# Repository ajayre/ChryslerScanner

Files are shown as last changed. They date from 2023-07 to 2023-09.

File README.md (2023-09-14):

# TJ Diag [][License]

GUI CCD 01

GUI SCI 01

GUI EngineTools 01

GUI BootstrapTools 01

<!----------------------------------------------------------------------------->

[Badge License]: https://img.shields.io/badge/License-GPLv3-blue.svg?style=for-the-badge
[GUI CCD 01]: https://chryslerccdsci.files.wordpress.com/2023/01/chryslerscanner_gui_ccd_01.png
[GUI SCI 01]: https://chryslerccdsci.files.wordpress.com/2023/01/chryslerscanner_gui_sci_01.png
[GUI EngineTools 01]: https://chryslerccdsci.files.wordpress.com/2023/01/chryslerscanner_gui_enginetools_01.png
[GUI BootstrapTools 01]: https://chryslerccdsci.files.wordpress.com/2023/01/chryslerscanner_gui_bootstraptools_01.png
[License]: LICENSE

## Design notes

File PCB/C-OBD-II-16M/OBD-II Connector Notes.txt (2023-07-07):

OBD-II CONNECTOR NOTES
======================

Right-angle OBD-II Connector sources (same part):
 - https://www.obd2-shop.eu/obd2pinblockmalepcbth-p-169.html?language=en
 - https://www.macchina.cc/catalog/parts/obd2-male-right-angle-pth-connector

Manufactured by:
 Comtech Electronic Co, Ltd. C-OBD-II-16M(90) - https://www.cct-elec.com/
 https://www.snapeda.com/parts/C-OBD-II-16M/Comtech%20Electronic%20Co.,%20LTD/view-part/

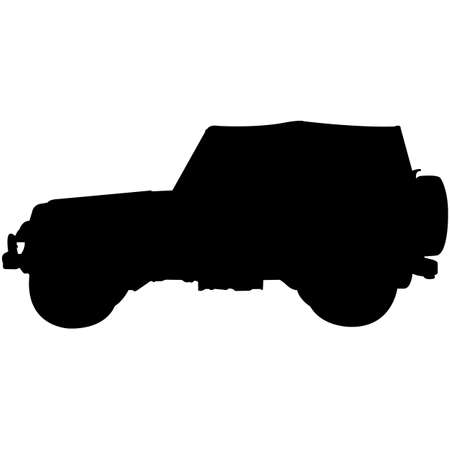
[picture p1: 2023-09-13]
PCB/Graphics/158078909-truck-silhouette-vector.jpg

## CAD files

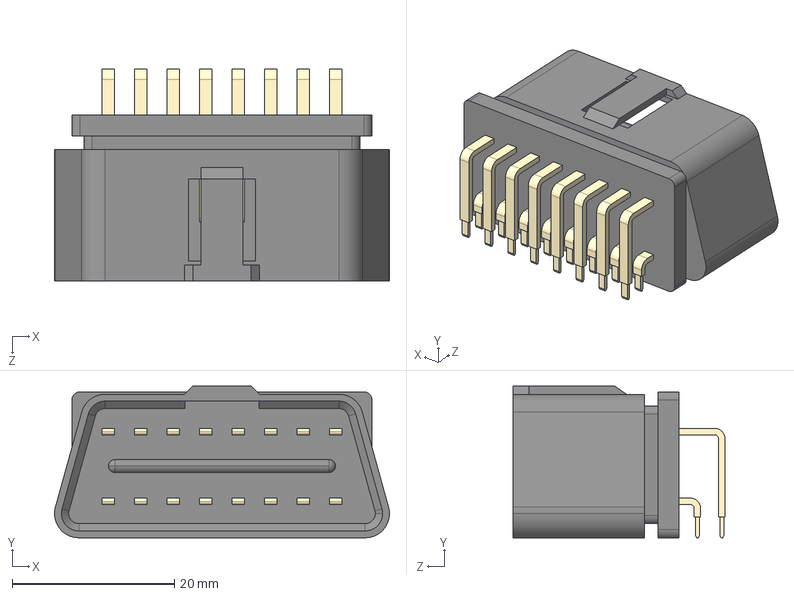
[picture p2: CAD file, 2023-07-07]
PCB/C-OBD-II-16M/C-OBD-II-16M.step
41.3 x 18.7 x 26.2 mm

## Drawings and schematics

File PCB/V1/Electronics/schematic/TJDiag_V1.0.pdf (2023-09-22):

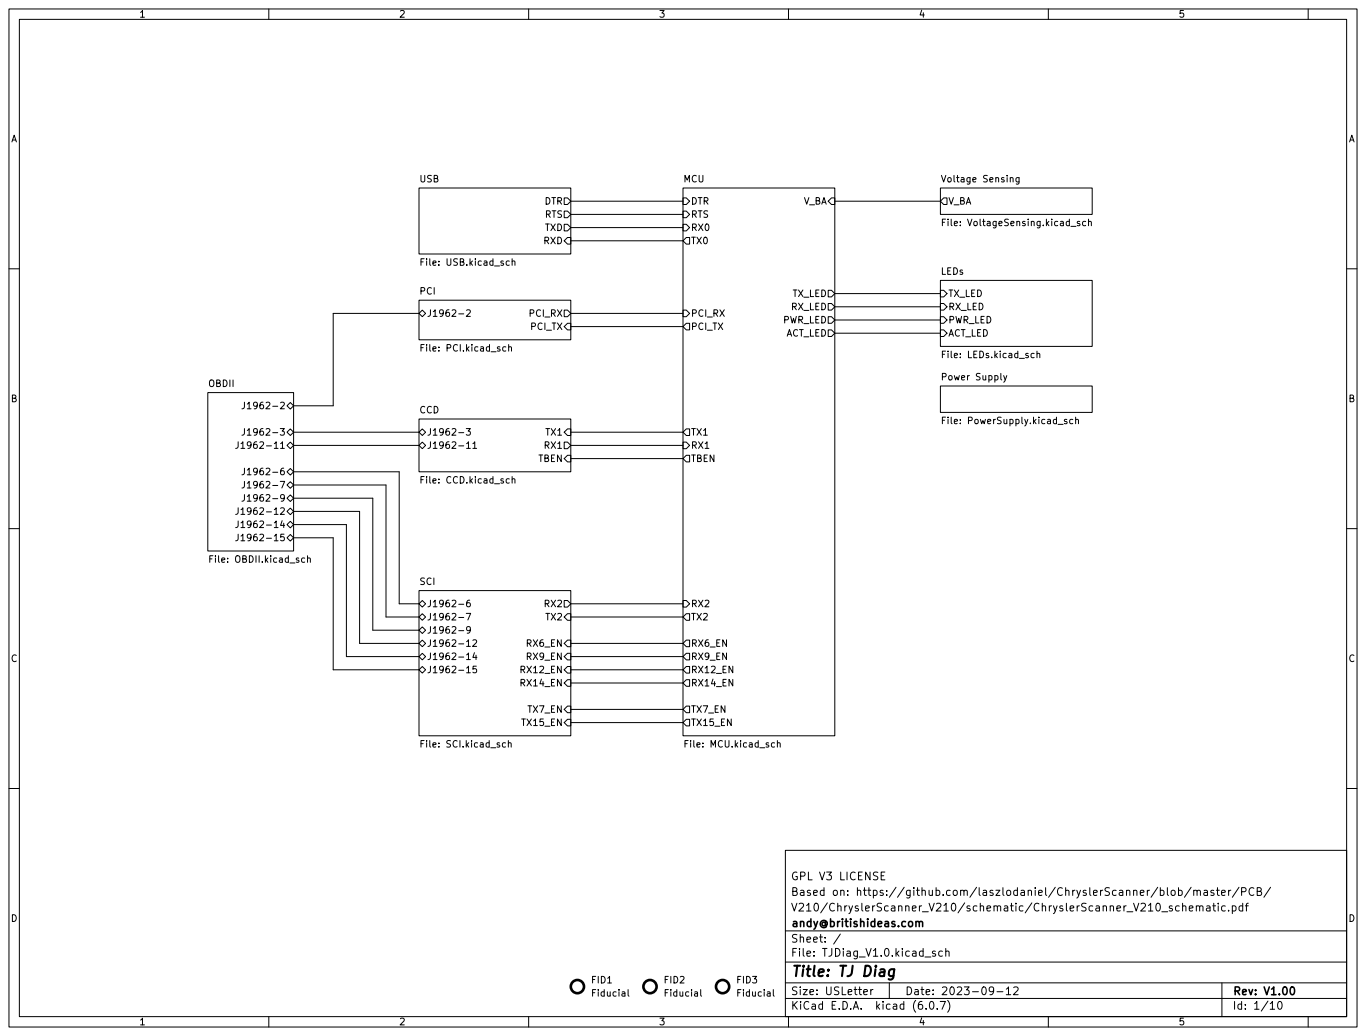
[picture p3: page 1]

LEDs File: LEDs.kicad_sch Power Supply

Based on: https://github.com/laszlodaniel/ChryslerScanner/blob/master/PCB/ GPL V3 LICENSE

V210/ChryslerScanner_V210/schematic/ChryslerScanner_V210_schematic.pdf
File: TJDiag_V1.0.kicad_sch Sheet: / andy@britishideas.com

Id: 1/10 Title: TJ Diag

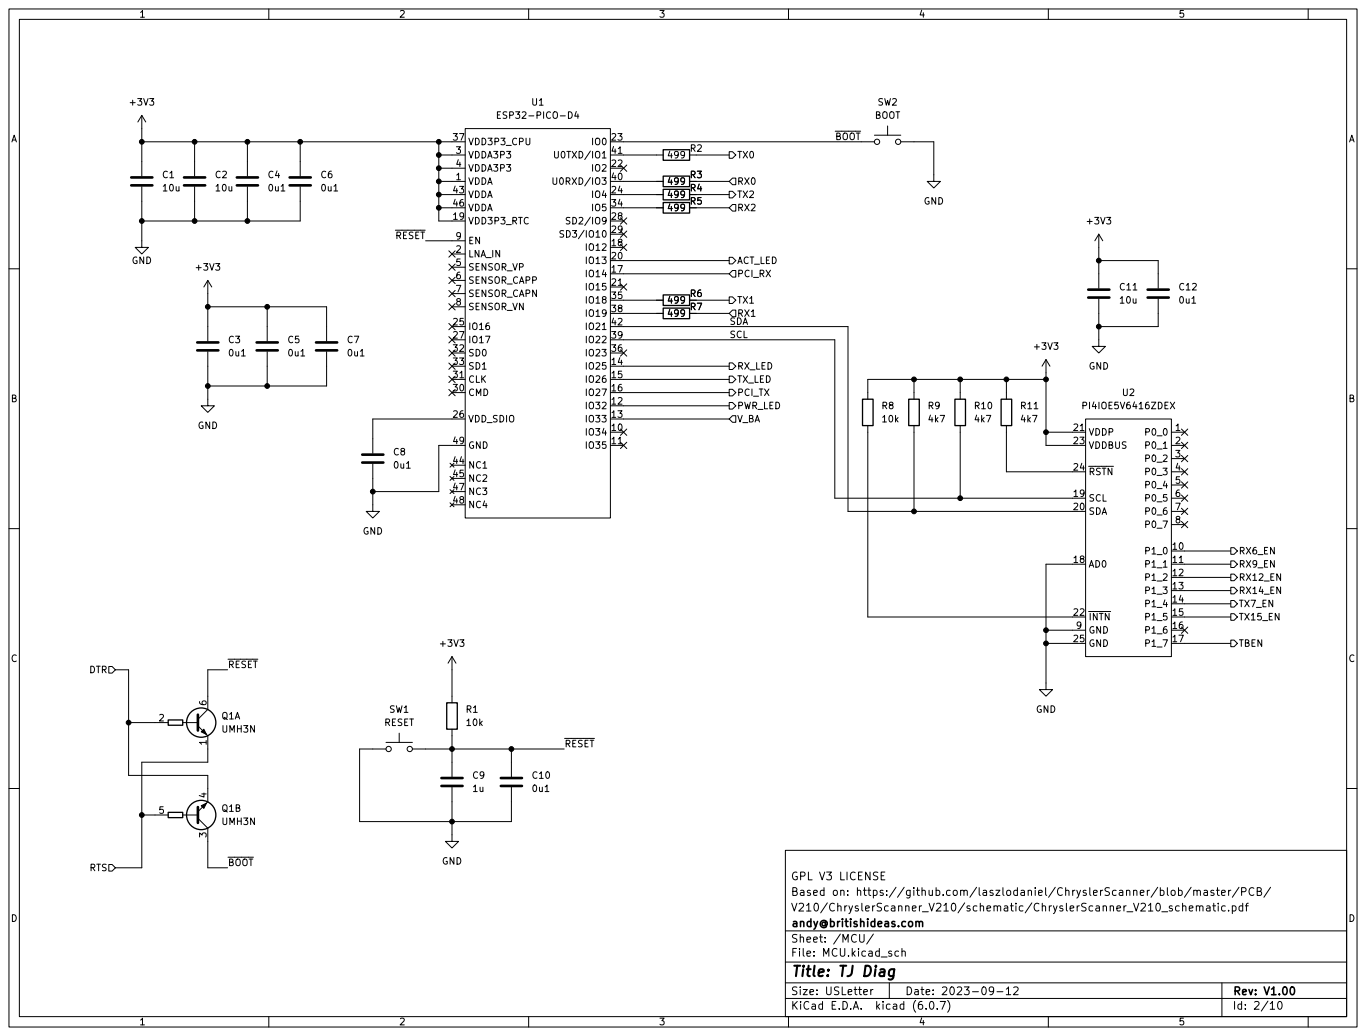
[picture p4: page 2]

Based on: https://github.com/laszlodaniel/ChryslerScanner/blob/master/PCB/ GPL V3 LICENSE

V210/ChryslerScanner_V210/schematic/ChryslerScanner_V210_schematic.pdf
File: MCU.kicad_sch Sheet: /MCU/ andy@britishideas.com

Id: 2/10 Title: TJ Diag

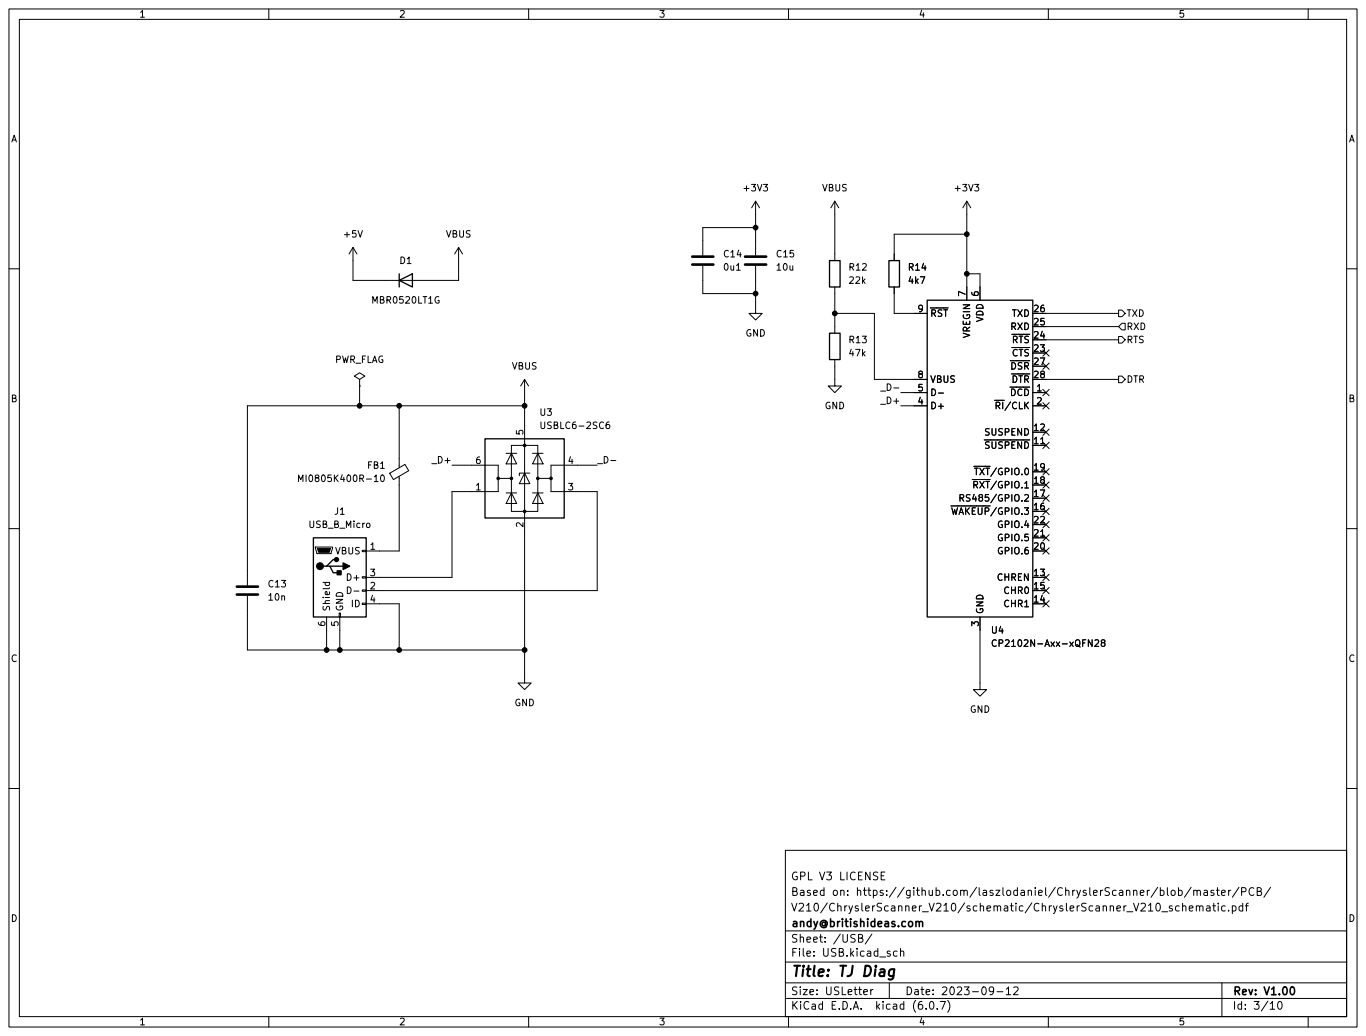
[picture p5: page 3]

Based on: https://github.com/laszlodaniel/ChryslerScanner/blob/master/PCB/ GPL V3 LICENSE

V210/ChryslerScanner_V210/schematic/ChryslerScanner_V210_schematic.pdf
File: USB.kicad_sch Sheet: /USB/ andy@britishideas.com

Id: 3/10 Title: TJ Diag

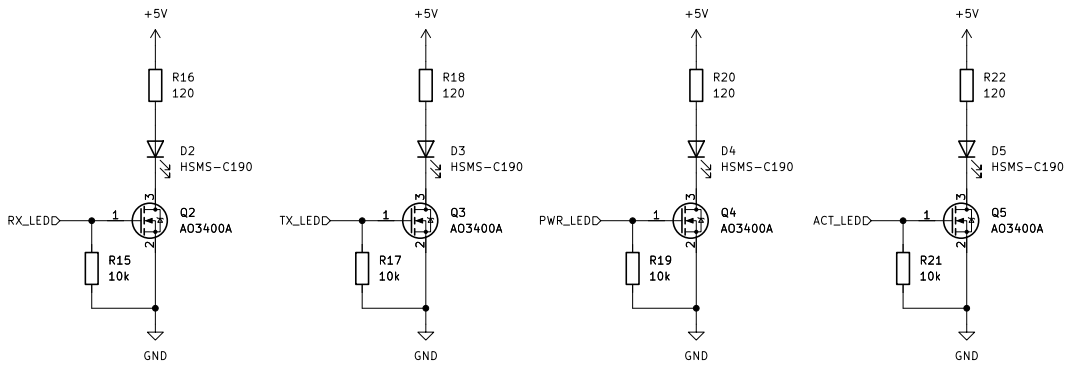
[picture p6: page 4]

Based on: https://github.com/laszlodaniel/ChryslerScanner/blob/master/PCB/ GPL V3 LICENSE

V210/ChryslerScanner_V210/schematic/ChryslerScanner_V210_schematic.pdf
File: LEDs.kicad_sch Sheet: /LEDs/ andy@britishideas.com

Id: 4/10 Title: TJ Diag

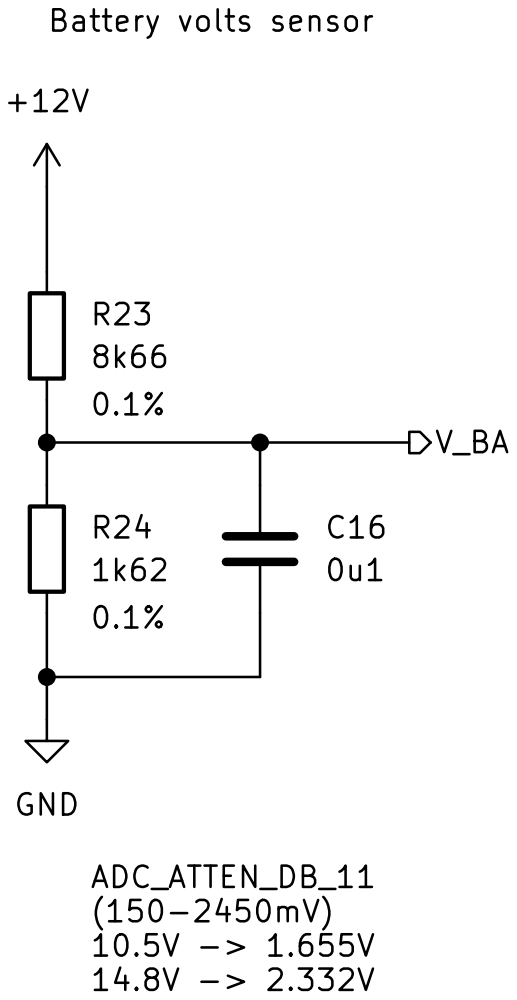
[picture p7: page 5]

Based on: https://github.com/laszlodaniel/ChryslerScanner/blob/master/PCB/ GPL V3 LICENSE

V210/ChryslerScanner_V210/schematic/ChryslerScanner_V210_schematic.pdf
andy@britishideas.com
Sheet: /Voltage Sensing/
File: VoltageSensing.kicad_sch
Id: 5/10 Title: TJ Diag

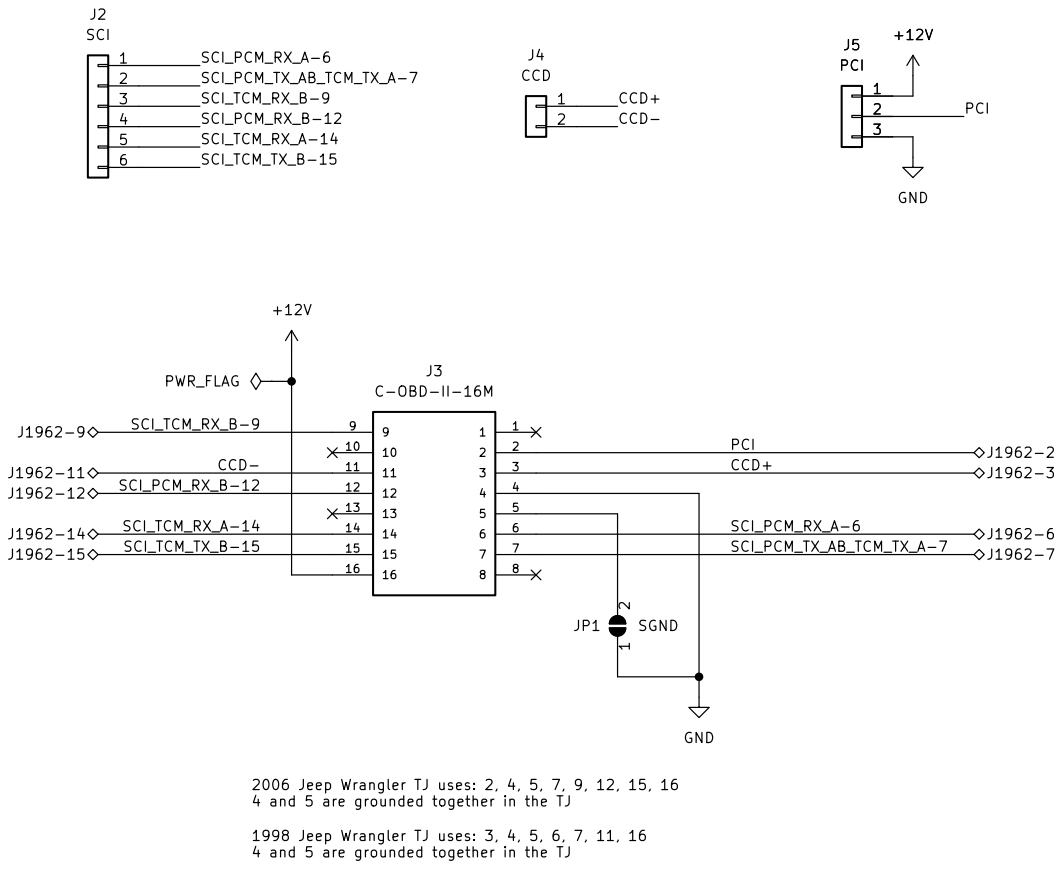
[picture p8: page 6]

4 and 5 are grounded together in the TJ

1998 Jeep Wrangler TJ uses: 3, 4, 5, 6, 7, 11, 16

Based on: https://github.com/laszlodaniel/ChryslerScanner/blob/master/PCB/ GPL V3 LICENSE

V210/ChryslerScanner_V210/schematic/ChryslerScanner_V210_schematic.pdf
File: OBDII.kicad_sch Sheet: /OBDII/ andy@britishideas.com

Id: 6/10 Title: TJ Diag

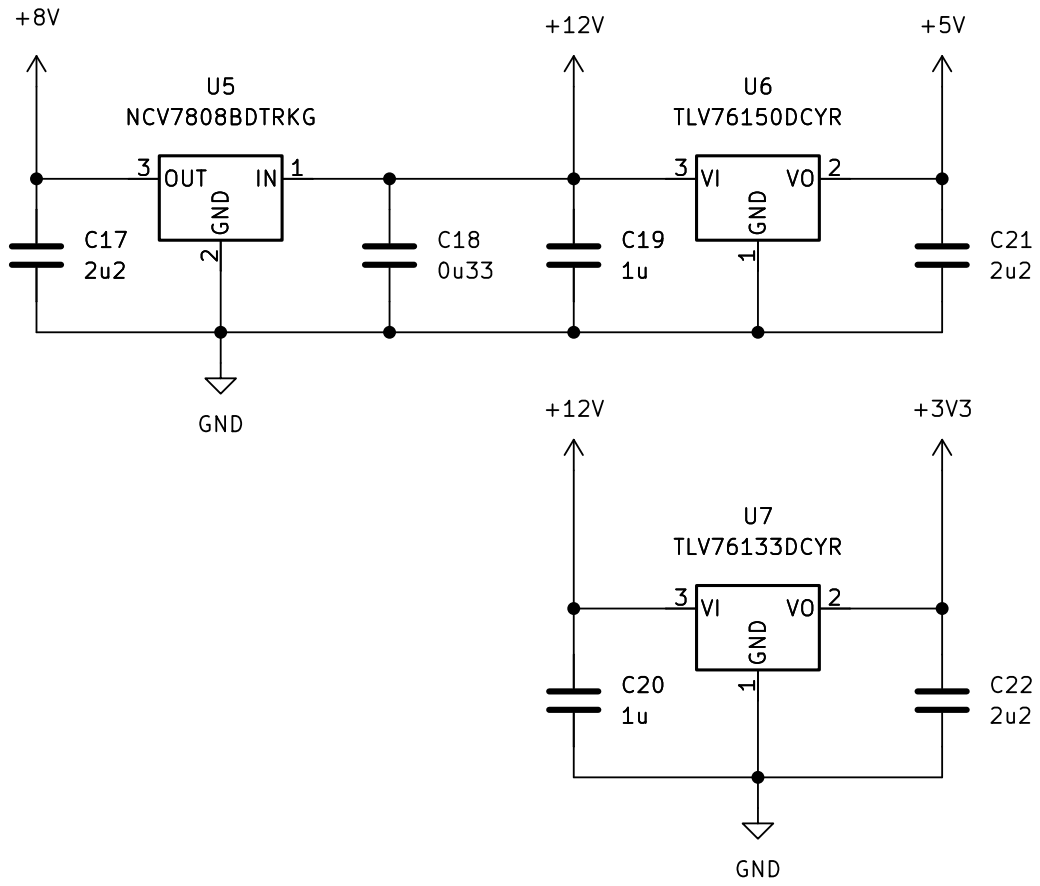
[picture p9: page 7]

Based on: https://github.com/laszlodaniel/ChryslerScanner/blob/master/PCB/ GPL V3 LICENSE andy@britishideas.com

Rev: V1.00 | D Date: 2023-09-12 KiCad E.D.A. kicad (6.0.7) Size: USLetter

Sheet: /Power Supply/
File: PowerSupply.kicad_sch
Id: 8/10 Title: TJ Diag

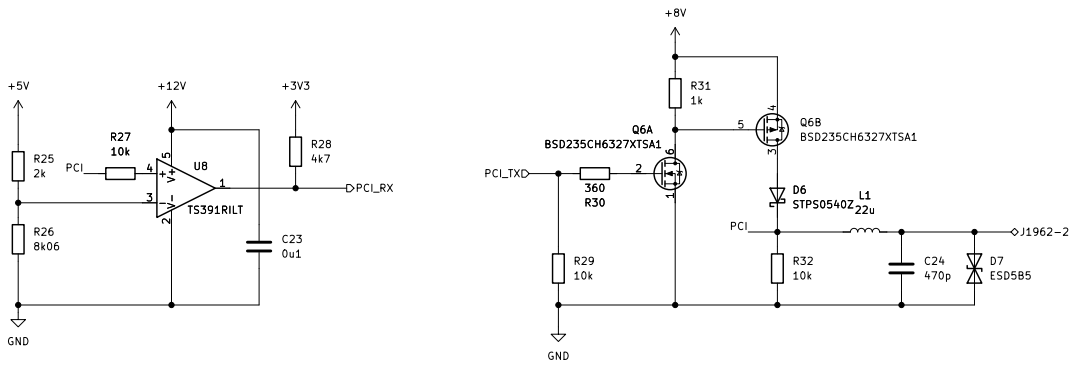
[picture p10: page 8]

Based on: https://github.com/laszlodaniel/ChryslerScanner/blob/master/PCB/ GPL V3 LICENSE

V210/ChryslerScanner_V210/schematic/ChryslerScanner_V210_schematic.pdf
File: PCI.kicad_sch Sheet: /PCI/ andy@britishideas.com

Id: 9/10 Title: TJ Diag

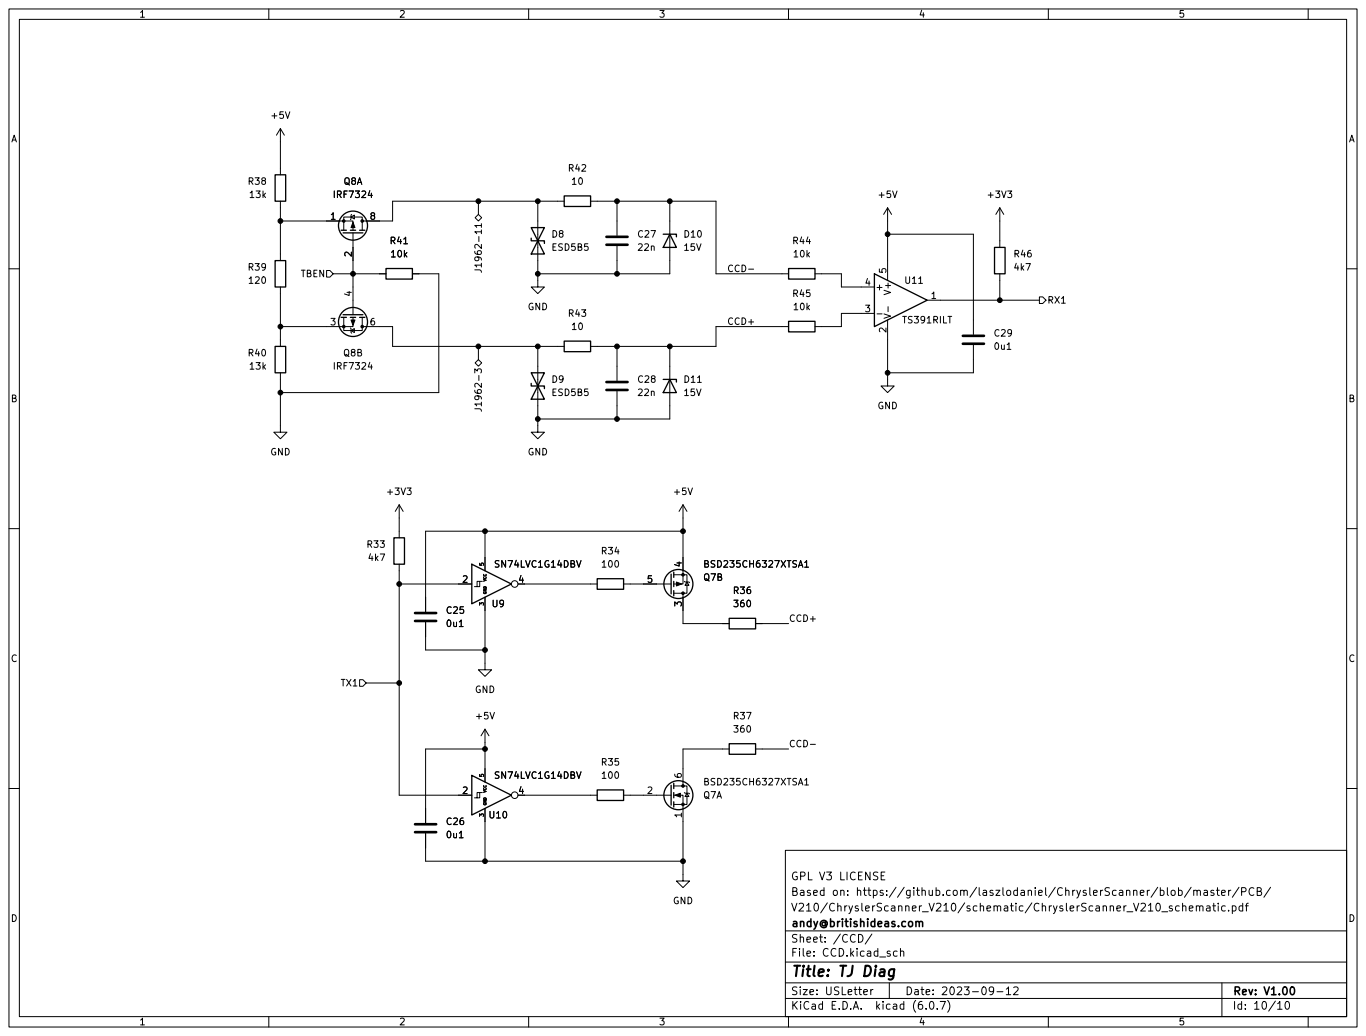
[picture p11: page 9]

Based on: https://github.com/laszlodaniel/ChryslerScanner/blob/master/PCB/ GPL V3 LICENSE

V210/ChryslerScanner_V210/schematic/ChryslerScanner_V210_schematic.pdf
File: CCD.kicad_sch Sheet: /CCD/ andy@britishideas.com

Id: 10/10 Title: TJ Diag

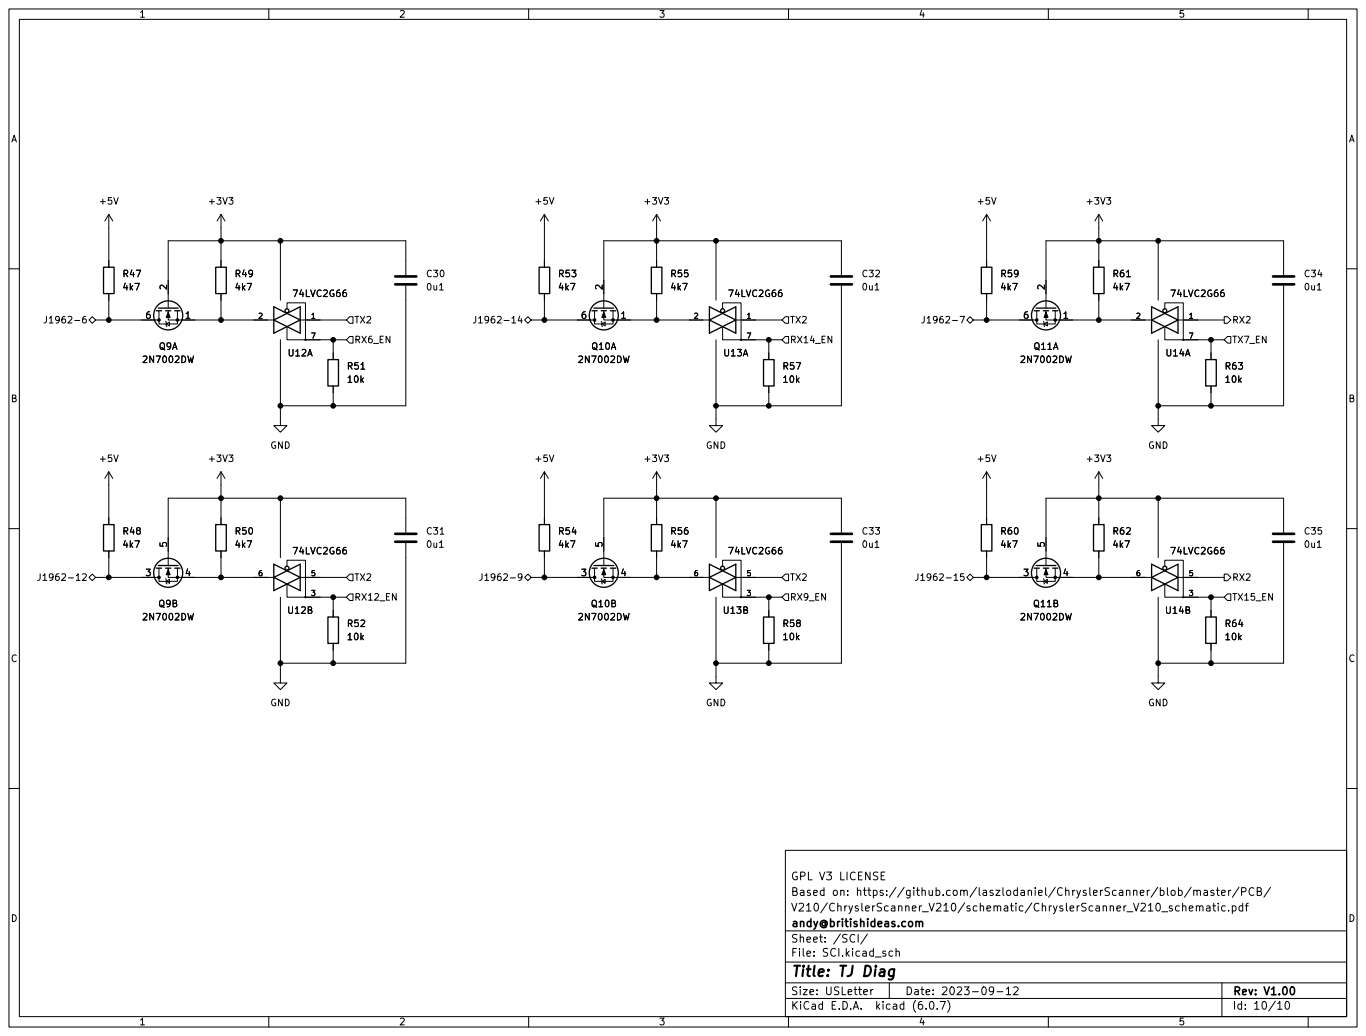
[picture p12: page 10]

Based on: https://github.com/laszlodaniel/ChryslerScanner/blob/master/PCB/ GPL V3 LICENSE

V210/ChryslerScanner_V210/schematic/ChryslerScanner_V210_schematic.pdf
File: SCI.kicad_sch Sheet: /SCI/ andy@britishideas.com

Id: 10/10 Title: TJ Diag

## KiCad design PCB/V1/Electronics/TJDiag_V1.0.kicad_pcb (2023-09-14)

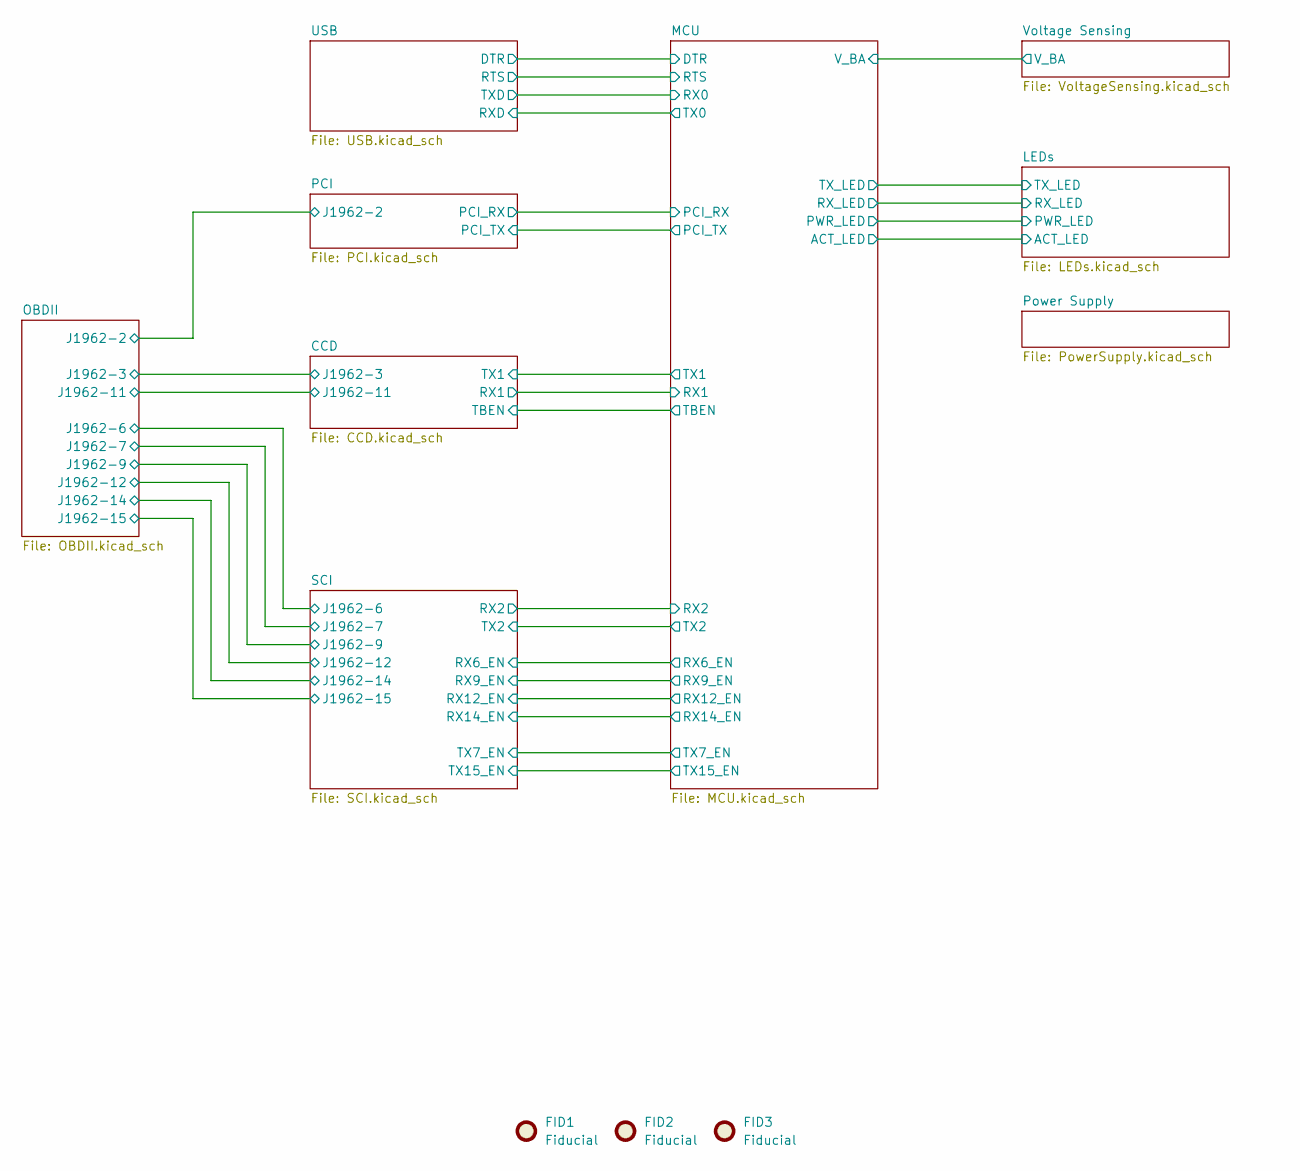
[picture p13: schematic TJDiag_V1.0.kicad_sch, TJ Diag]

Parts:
FID1, FID2, FID3: Fiducial; Fiducial_0.5mm_Mask1mm

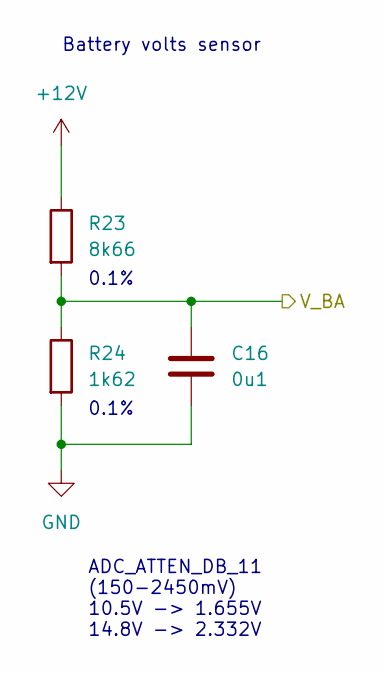
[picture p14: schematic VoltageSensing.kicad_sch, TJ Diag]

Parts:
C16: 0u1; C_0603_1608Metric
R23: 8k66; R_0603_1608Metric
R24: 1k62; R_0603_1608Metric

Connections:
/MCU/V_BA: C16.1, R23.2, R24.1; also elsewhere on the board
GND: C16.2, R24.2; also elsewhere on the board

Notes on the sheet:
ADC_ATTEN_DB_11 (150-2450mV) 10.5V -> 1.655V 14.8V -> 2.332V
0.1%
Battery volts sensor

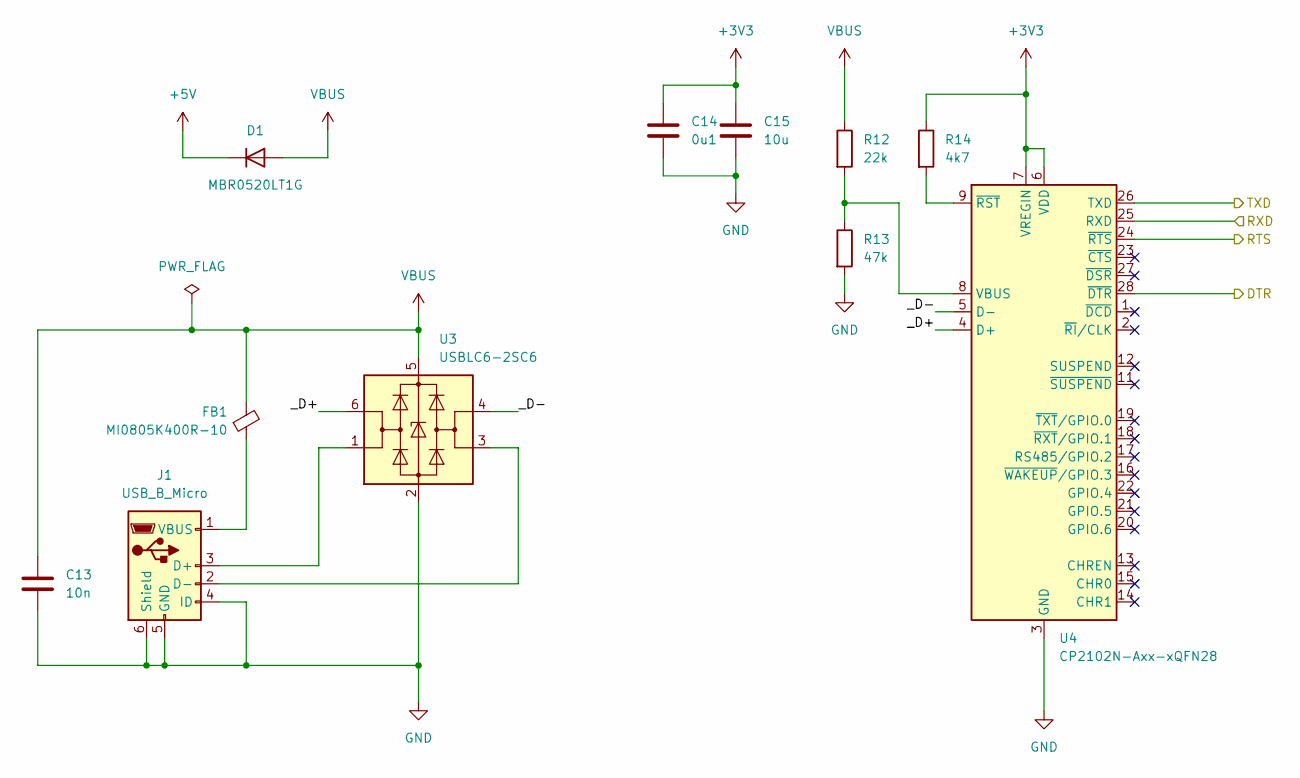
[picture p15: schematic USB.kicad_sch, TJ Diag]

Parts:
C13: 10n; C_0603_1608Metric
C14: 0u1; C_0603_1608Metric
C15: 10u; C_0603_1608Metric
D1: MBR0520LT1G; SOD-123
FB1: MI0805K400R-10; R_0805_2012Metric
J1: USB_B_Micro; USB_Micro-B_Amphenol_10103594-0001LF_Horizontal
R12: 22k; R_0603_1608Metric
R13: 47k; R_0603_1608Metric
R14: 4k7; R_0603_1608Metric
U3: USBLC6-2SC6; SOT-23-6
U4: CP2102N-Axx-xQFN28; QFN-28-1EP_5x5mm_P0.5mm_EP3.35x3.35mm

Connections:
+3V3: C14.1, C15.1, R14.1, U4.6 (VDD), U4.7 (VREGIN); also elsewhere on the board
+5V: D1.1 (K); also elsewhere on the board
/MCU/DTR: U4.28 (~DTR); also elsewhere on the board
/MCU/RTS: U4.24 (~RTS); also elsewhere on the board
/MCU/RX0: U4.26 (TXD); also elsewhere on the board
/MCU/TX0: U4.25 (RXD); also elsewhere on the board
/USB/_D+: U3.6 (I/O1), U4.4 (D+)
/USB/_D-: U3.4 (I/O2), U4.5 (D-)
GND: C13.2, C14.2, C15.2, J1.4 (ID), J1.5 (GND), J1.6 (Shield), R13.2, U3.2 (GND), U4.3 (GND), U4.29 (GND); also elsewhere on the board
unnamed: FB1.1, J1.1 (VBUS)
unnamed: J1.2 (D-), U3.3 (I/O2)
unnamed: J1.3 (D+), U3.1 (I/O1)
unnamed: R12.2, R13.1, U4.8 (VBUS)
unnamed: R14.2, U4.9 (~RST)
VBUS: C13.1, D1.2 (A), FB1.2, R12.1, U3.5 (VBUS)

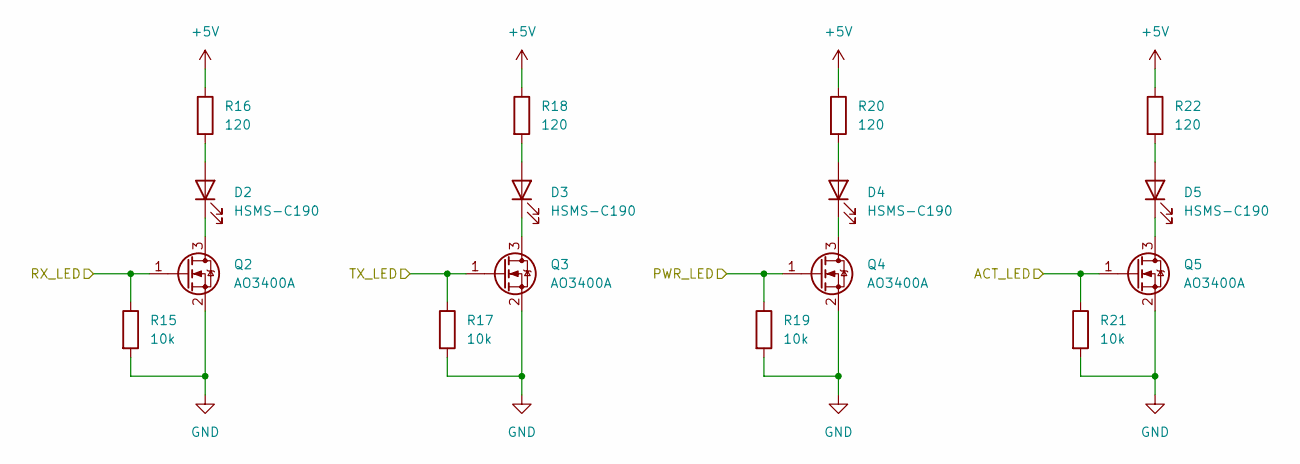
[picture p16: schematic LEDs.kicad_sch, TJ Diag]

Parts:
D2, D3, D4, D5: HSMS-C190; LED_0603_1608Metric
Q2, Q3, Q4, Q5: AO3400A; SOT-23
R15, R17, R19, R21: 10k; R_0603_1608Metric
R16, R18, R20, R22: 120; R_0603_1608Metric

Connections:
+5V: R16.1, R18.1, R20.1, R22.1; also elsewhere on the board
/LEDs/ACT_LED: Q5.1 (G), R21.1; also elsewhere on the board
/LEDs/PWR_LED: Q4.1 (G), R19.1; also elsewhere on the board
/LEDs/RX_LED: Q2.1 (G), R15.1; also elsewhere on the board
/LEDs/TX_LED: Q3.1 (G), R17.1; also elsewhere on the board
GND: Q2.2 (S), Q3.2 (S), Q4.2 (S), Q5.2 (S), R15.2, R17.2, R19.2, R21.2; also elsewhere on the board
unnamed: D2.1 (K), Q2.3 (D)
unnamed: D2.2 (A), R16.2
unnamed: D3.1 (K), Q3.3 (D)
unnamed: D3.2 (A), R18.2
unnamed: D4.1 (K), Q4.3 (D)
unnamed: D4.2 (A), R20.2
unnamed: D5.1 (K), Q5.3 (D)
unnamed: D5.2 (A), R22.2

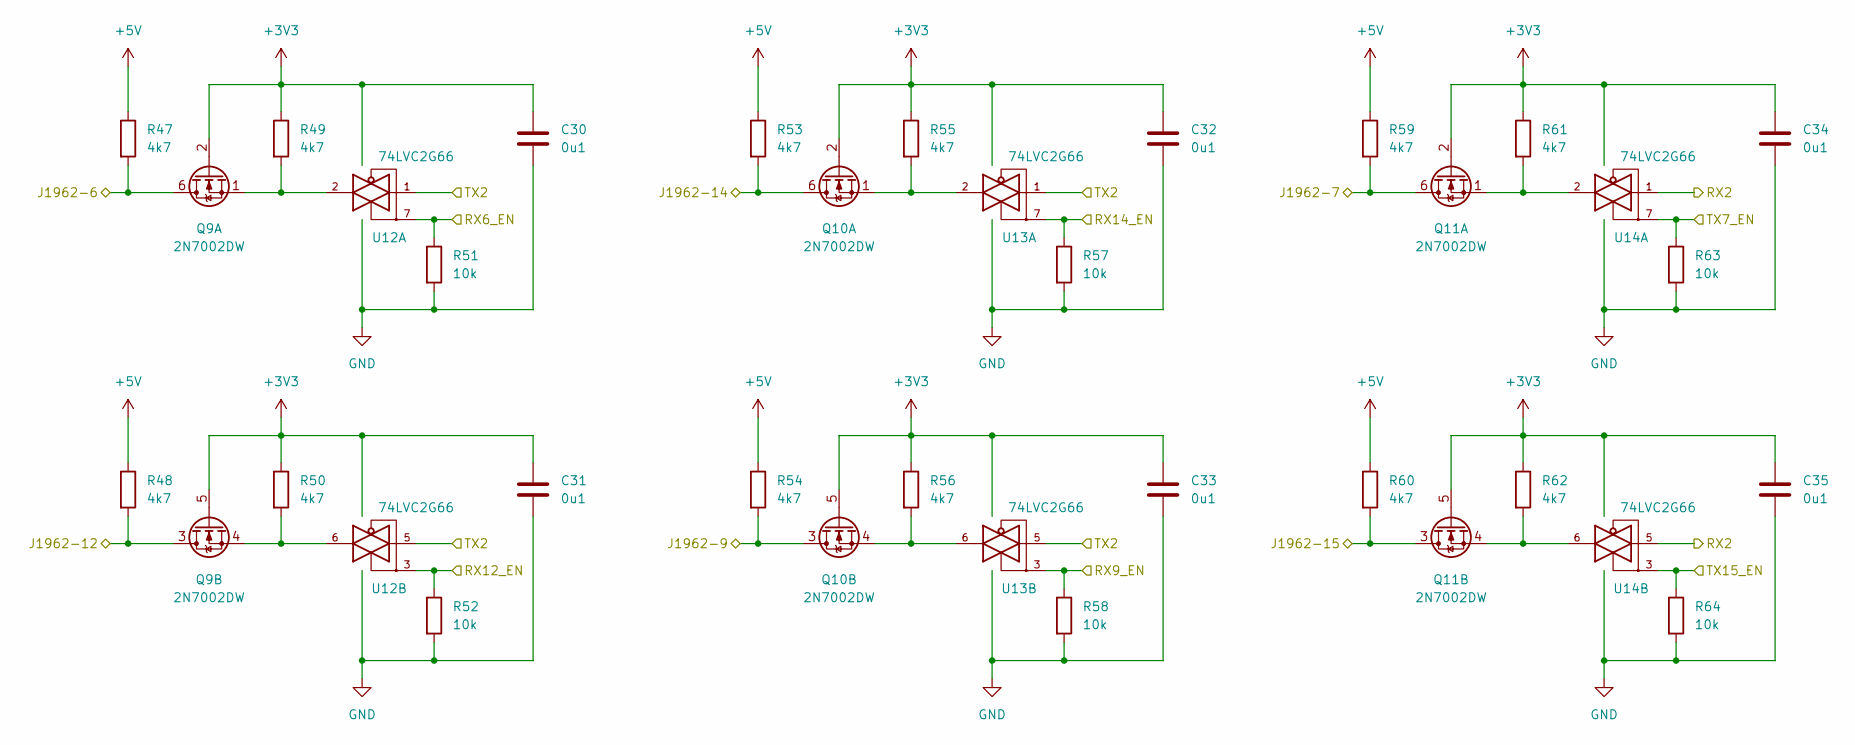
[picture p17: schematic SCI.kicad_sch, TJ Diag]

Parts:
C30, C31, C32, C33, C34, C35: 0u1; C_0603_1608Metric
Q9, Q10, Q11: 2N7002DW; SOT-363_SC-70-6
R47, R48, R49, R50, R53, R54, R55, R56, R59, R60, R61, R62: 4k7; R_0603_1608Metric
R51, R52, R57, R58, R63, R64: 10k; R_0603_1608Metric
U12, U13, U14: 74LVC2G66; TSSOP-8_3x3mm_P0.65mm

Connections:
+3V3: C30.1, C31.1, C32.1, C33.1, C34.1, C35.1, Q9.2 (G), Q9.5 (G), Q10.2 (G), Q10.5 (G), Q11.2 (G), Q11.5 (G), R49.1, R50.1, R55.1, R56.1, R61.1, R62.1, U12.8 (VCC), U13.8 (VCC), U14.8 (VCC); also elsewhere on the board
+5V: R47.1, R48.1, R53.1, R54.1, R59.1, R60.1; also elsewhere on the board
/MCU/RX2: U14.1, U14.5; also elsewhere on the board
/MCU/RX6_EN: R51.1, U12.7; also elsewhere on the board
/MCU/RX9_EN: R58.1, U13.3; also elsewhere on the board
/MCU/RX12_EN: R52.1, U12.3; also elsewhere on the board
/MCU/RX14_EN: R57.1, U13.7; also elsewhere on the board
/MCU/TX2: U12.1, U12.5, U13.1, U13.5; also elsewhere on the board
/MCU/TX7_EN: R63.1, U14.7; also elsewhere on the board
/MCU/TX15_EN: R64.1, U14.3; also elsewhere on the board
/OBDII/SCI_PCM_RX_A-6: Q9.6 (D), R47.2; also elsewhere on the board
/OBDII/SCI_PCM_RX_B-12: Q9.3 (D), R48.2; also elsewhere on the board
/OBDII/SCI_PCM_TX_AB_TCM_TX_A-7: Q11.6 (D), R59.2; also elsewhere on the board
/OBDII/SCI_TCM_RX_A-14: Q10.6 (D), R53.2; also elsewhere on the board
/OBDII/SCI_TCM_RX_B-9: Q10.3 (D), R54.2; also elsewhere on the board
/OBDII/SCI_TCM_TX_B-15: Q11.3 (D), R60.2; also elsewhere on the board
GND: C30.2, C31.2, C32.2, C33.2, C34.2, C35.2, R51.2, R52.2, R57.2, R58.2, R63.2, R64.2, U12.4 (GND), U13.4 (GND), U14.4 (GND); also elsewhere on the board
unnamed: Q9.1 (S), R49.2, U12.2
unnamed: Q9.4 (S), R50.2, U12.6
unnamed: Q10.1 (S), R55.2, U13.2
unnamed: Q10.4 (S), R56.2, U13.6
unnamed: Q11.1 (S), R61.2, U14.2
unnamed: Q11.4 (S), R62.2, U14.6

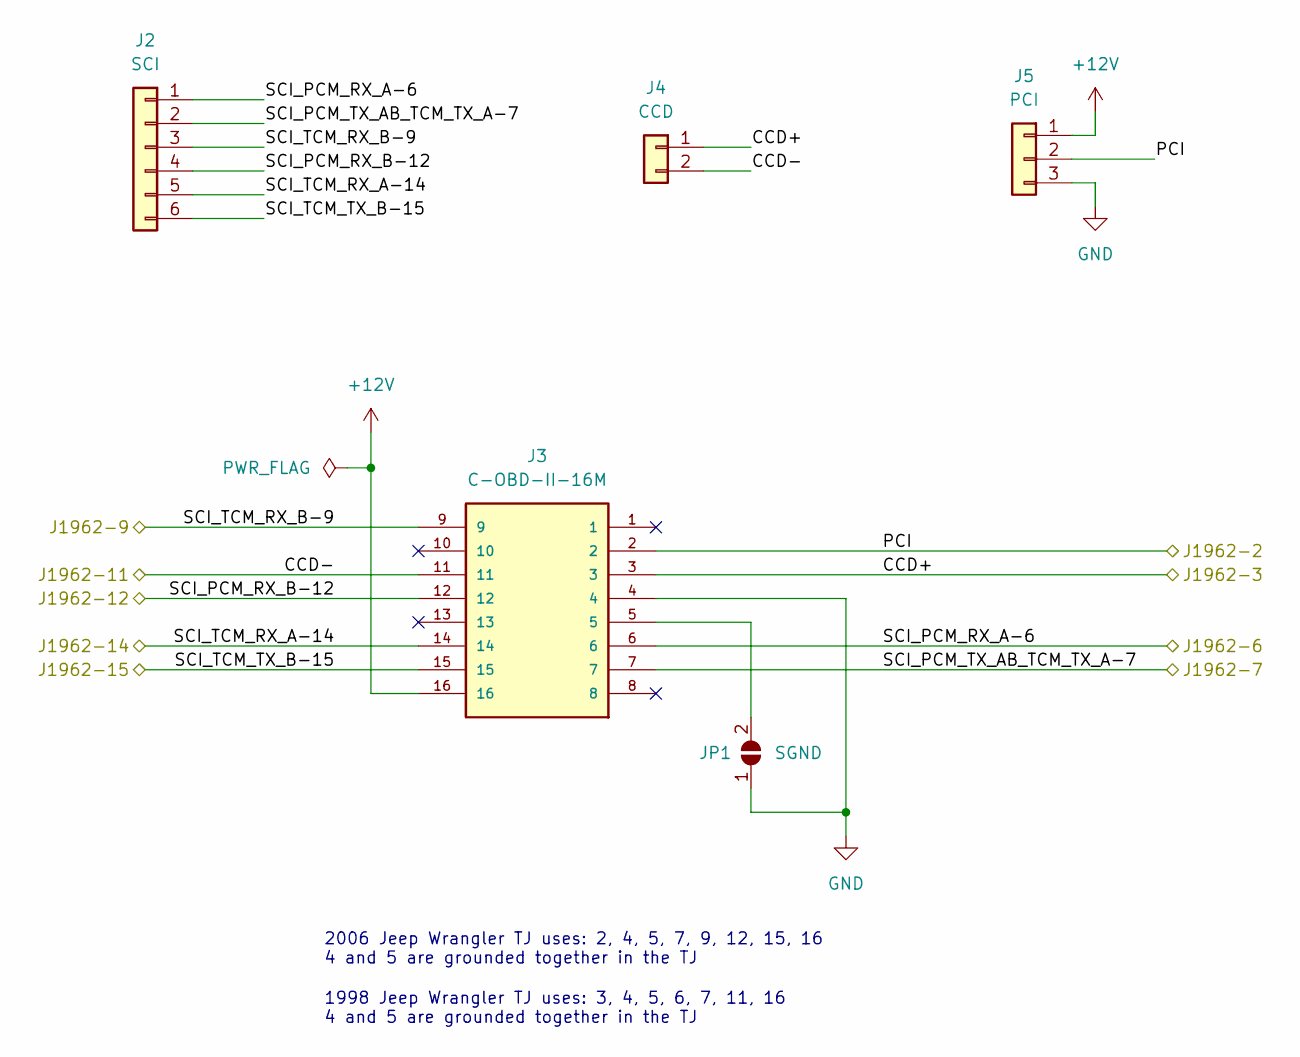
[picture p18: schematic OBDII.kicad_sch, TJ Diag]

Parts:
J2: SCI; PinHeader_1x06_P2.54mm_Vertical
J3: C-OBD-II-16M; COMTECH_C-OBD-II-16M; PARTREV A
J4: CCD; PinHeader_1x02_P2.54mm_Vertical
J5: PCI; PinHeader_1x03_P2.54mm_Vertical
JP1: SGND; SolderJumper-2_P1.3mm_Open_TrianglePad1.0x1.5mm

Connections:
/OBDII/CCD+: J3.3, J4.1; also elsewhere on the board
/OBDII/CCD-: J3.11, J4.2; also elsewhere on the board
/OBDII/PCI: J3.2, J5.2; also elsewhere on the board
/OBDII/SCI_PCM_RX_A-6: J2.1, J3.6; also elsewhere on the board
/OBDII/SCI_PCM_RX_B-12: J2.4, J3.12; also elsewhere on the board
/OBDII/SCI_PCM_TX_AB_TCM_TX_A-7: J2.2, J3.7; also elsewhere on the board
/OBDII/SCI_TCM_RX_A-14: J2.5, J3.14; also elsewhere on the board
/OBDII/SCI_TCM_RX_B-9: J2.3, J3.9; also elsewhere on the board
/OBDII/SCI_TCM_TX_B-15: J2.6, J3.15; also elsewhere on the board
GND: J3.4, J5.3, JP1.1 (A); also elsewhere on the board
unnamed: J3.5, JP1.2 (B)

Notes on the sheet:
2006 Jeep Wrangler TJ uses: 2, 4, 5, 7, 9, 12, 15, 16 4 and 5 are grounded together in the TJ
1998 Jeep Wrangler TJ uses: 3, 4, 5, 6, 7, 11, 16 4 and 5 are grounded together in the TJ

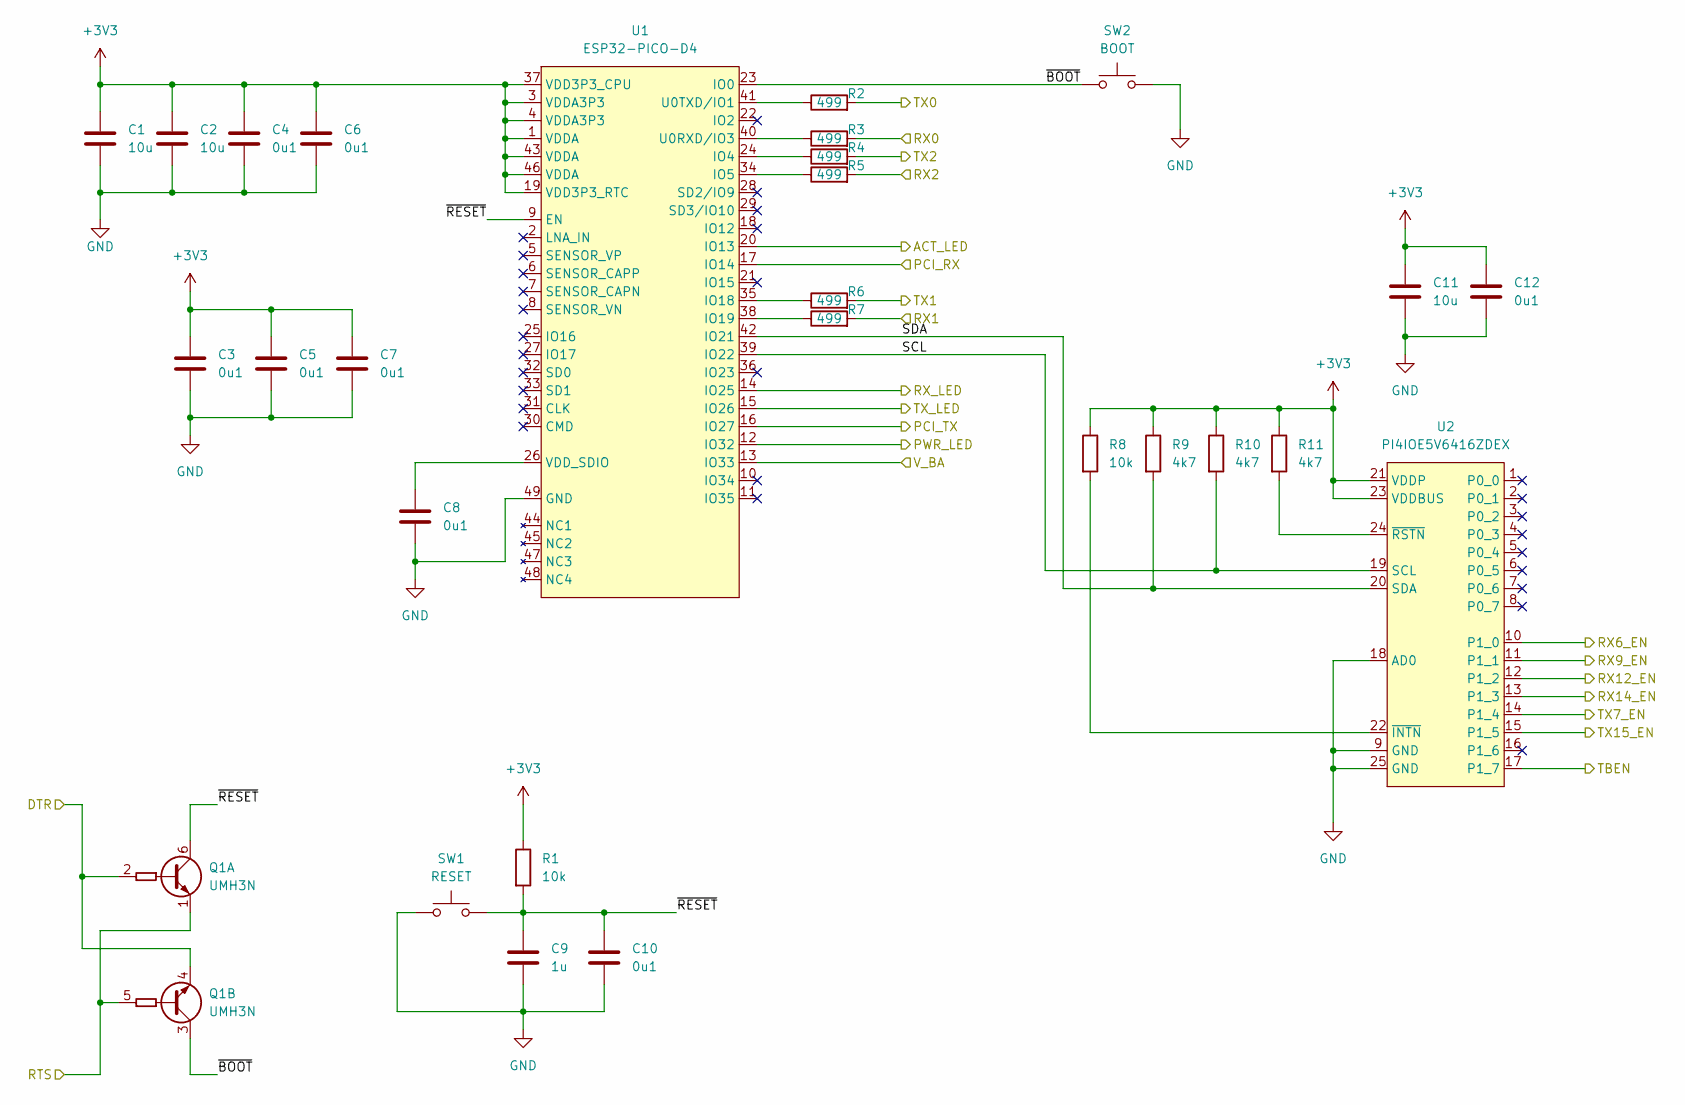
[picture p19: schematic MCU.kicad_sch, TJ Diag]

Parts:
C1, C2, C11: 10u; C_0603_1608Metric
C3, C4, C5, C6, C7, C8, C10, C12: 0u1; C_0603_1608Metric
C9: 1u; C_0603_1608Metric
Q1: UMH3N; SOT-363_SC-70-6
R1, R8: 10k; R_0603_1608Metric
R2, R3, R4, R5, R6, R7: 499; R_0603_1608Metric
R9, R10, R11: 4k7; R_0603_1608Metric
SW1: RESET; TL6330 Tactile Switch
SW2: BOOT; TL6330 Tactile Switch
U1: ESP32-PICO-D4; QFN-48-1EP_7x7mm_P0.5mm_EP5.15x5.15mm_ThermalVias
U2: PI4IOE5V6416ZDEX; QFN-24-1EP_4x4mm_P0.5mm_EP2.15x2.15mm_ThermalVias

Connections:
+3V3: C1.1, C2.1, C3.1, C4.1, C5.1, C6.1, C7.1, C11.1, C12.1, R1.1, R8.1, R9.1, R10.1, R11.1, U1.1 (VDDA), U1.3 (VDDA3P3), U1.4 (VDDA3P3), U1.19 (VDD3P3_RTC), U1.37 (VDD3P3_CPU), U1.43 (VDDA), U1.46 (VDDA), U2.21 (VDDP), U2.23 (VDDBUS); also elsewhere on the board
/CCD/RX1: R7.2; also elsewhere on the board
/CCD/TBEN: U2.17 (P1_7); also elsewhere on the board
/CCD/TX1: R6.2; also elsewhere on the board
/LEDs/ACT_LED: U1.20 (IO13); also elsewhere on the board
/LEDs/PWR_LED: U1.12 (IO32); also elsewhere on the board
/LEDs/RX_LED: U1.14 (IO25); also elsewhere on the board
/LEDs/TX_LED: U1.15 (IO26); also elsewhere on the board
/MCU/DTR: Q1.2 (B1), Q1.4 (E2); also elsewhere on the board
/MCU/PCI_RX: U1.17 (IO14); also elsewhere on the board
/MCU/PCI_TX: U1.16 (IO27); also elsewhere on the board
/MCU/RTS: Q1.1 (E1), Q1.5 (B2); also elsewhere on the board
/MCU/RX0: R3.2; also elsewhere on the board
/MCU/RX2: R5.2; also elsewhere on the board
/MCU/RX6_EN: U2.10 (P1_0); also elsewhere on the board
/MCU/RX9_EN: U2.11 (P1_1); also elsewhere on the board
/MCU/RX12_EN: U2.12 (P1_2); also elsewhere on the board
/MCU/RX14_EN: U2.13 (P1_3); also elsewhere on the board
/MCU/SCL: R10.2, U1.39 (IO22), U2.19 (SCL)
/MCU/SDA: R9.2, U1.42 (IO21), U2.20 (SDA)
/MCU/TX0: R2.2; also elsewhere on the board
/MCU/TX2: R4.2; also elsewhere on the board
/MCU/TX7_EN: U2.14 (P1_4); also elsewhere on the board
/MCU/TX15_EN: U2.15 (P1_5); also elsewhere on the board
/MCU/V_BA: U1.13 (IO33); also elsewhere on the board
/MCU/~BOOT: Q1.3 (C2), SW2.1, U1.23 (IO0)
/MCU/~RESET: C9.1, C10.1, Q1.6 (C1), R1.2, SW1.2, U1.9 (EN)
GND: C1.2, C2.2, C3.2, C4.2, C5.2, C6.2, C7.2, C8.2, C9.2, C10.2, C11.2, C12.2, SW1.1, SW2.2, U1.49 (GND), U2.9 (GND), U2.18 (AD0), U2.25 (GND); also elsewhere on the board
unnamed: C8.1, U1.26 (VDD_SDIO)
unnamed: R2.1, U1.41 (U0TXD/IO1)
unnamed: R3.1, U1.40 (U0RXD/IO3)
unnamed: R4.1, U1.24 (IO4)
unnamed: R5.1, U1.34 (IO5)
unnamed: R6.1, U1.35 (IO18)
unnamed: R7.1, U1.38 (IO19)
unnamed: R8.2, U2.22 (~INTN)
unnamed: R11.2, U2.24 (~RSTN)

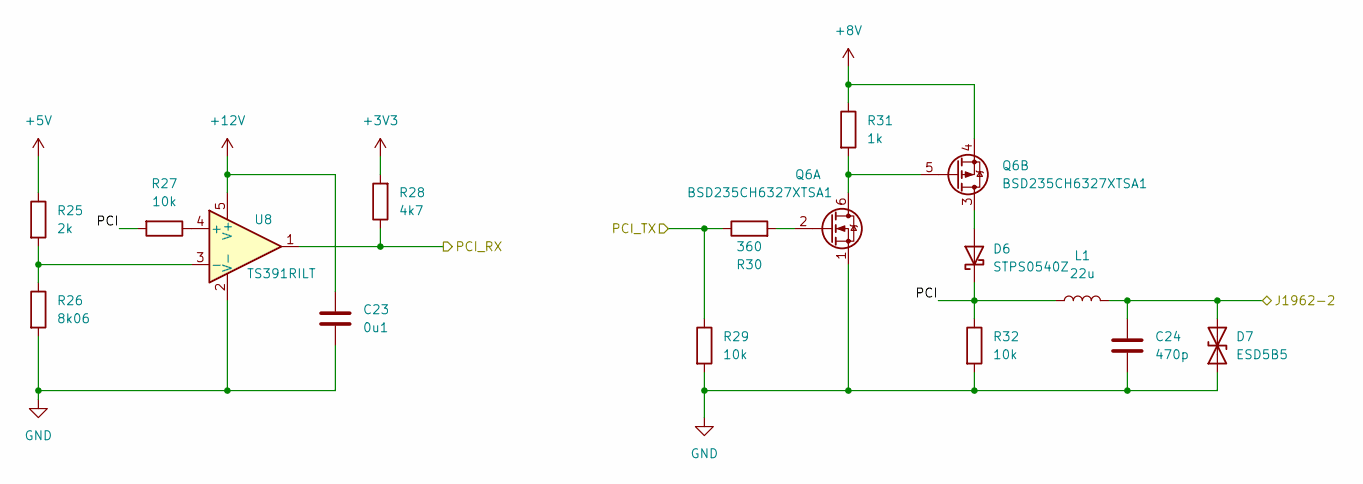
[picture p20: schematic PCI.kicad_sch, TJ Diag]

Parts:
C23: 0u1; C_0603_1608Metric
C24: 470p; C_0603_1608Metric
D6: STPS0540Z; SOD-123
D7: ESD5B5; D_SOD-523
L1: 22u; L_0805_2012Metric
Q6: BSD235CH6327XTSA1; SOT-363_SC-70-6
R25: 2k; R_0603_1608Metric
R26: 8k06; R_0603_1608Metric
R27, R29, R32: 10k; R_0603_1608Metric
R28: 4k7; R_0603_1608Metric
R30: 360; R_0603_1608Metric
R31: 1k; R_0603_1608Metric
U8: TS391RILT; SOT-23-5

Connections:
+3V3: R28.2; also elsewhere on the board
+5V: R25.1; also elsewhere on the board
+8V: Q6.4 (1), R31.1; also elsewhere on the board
/MCU/PCI_RX: R28.1, U8.1; also elsewhere on the board
/MCU/PCI_TX: R29.1, R30.1; also elsewhere on the board
/OBDII/PCI: C24.1, D7.2 (A2), L1.2; also elsewhere on the board
/PCI/PCI: D6.1 (K), L1.1, R27.2, R32.1
GND: C23.2, C24.2, D7.1 (A1), Q6.1 (S), R26.2, R29.2, R32.2, U8.2 (V-); also elsewhere on the board
unnamed: D6.2 (A), Q6.3 (D)
unnamed: Q6.2 (G), R30.2
unnamed: Q6.5 (G), Q6.6 (D), R31.2
unnamed: R25.2, R26.1, U8.3 (-)
unnamed: R27.1, U8.4 (+)

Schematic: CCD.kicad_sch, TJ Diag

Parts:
C25, C26, C29: 0u1; C_0603_1608Metric
C27, C28: 22n; C_0603_1608Metric
D8, D9: ESD5B5; D_SOD-523
D10, D11: 15V; D_SOD-323
Q7: BSD235CH6327XTSA1; SOT-363_SC-70-6
Q8: IRF7324; SOIC-8_3.9x4.9mm_P1.27mm
R33, R46: 4k7; R_0603_1608Metric
R34, R35: 100; R_0603_1608Metric
R36, R37: 360; R_0603_1608Metric
R38, R40: 13k; R_0603_1608Metric
R39: 120; R_0603_1608Metric
R41, R44, R45: 10k; R_0603_1608Metric
R42, R43: 10; R_0603_1608Metric
U9, U10: SN74LVC1G14DBV; SOT-23-5
U11: TS391RILT; SOT-23-5

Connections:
+3V3: R33.1, R46.1; also elsewhere on the board
+5V: C25.1, C26.1, C29.1, Q7.4 (1), R38.1, U9.5 (VCC), U10.5 (VCC), U11.5 (V+); also elsewhere on the board
/CCD/CCD+: C28.1, D11.1 (K), R36.1, R43.1, R45.2
/CCD/CCD-: C27.1, D10.1 (K), R37.1, R42.1, R44.2
/CCD/RX1: R46.2, U11.1; also elsewhere on the board
/CCD/TBEN: Q8.2 (G1), Q8.4 (G2), R41.1; also elsewhere on the board
/CCD/TX1: R33.2, U9.2, U10.2; also elsewhere on the board
/OBDII/CCD+: D9.2 (A2), Q8.5 (D2), Q8.6 (D2), R43.2; also elsewhere on the board
/OBDII/CCD-: D8.2 (A2), Q8.7 (D1), Q8.8 (D1), R42.2; also elsewhere on the board
GND: C25.2, C26.2, C27.2, C28.2, C29.2, D8.1 (A1), D9.1 (A1), D10.2 (A), D11.2 (A), Q7.1 (S), R40.2, R41.2, U9.3 (GND), U10.3 (GND), U11.2 (V-); also elsewhere on the board
unnamed: Q7.2 (G), R35.1
unnamed: Q7.3 (D), R36.2
unnamed: Q7.5 (G), R34.1
unnamed: Q7.6 (D), R37.2
unnamed: Q8.1 (S1), R38.2, R39.1
unnamed: Q8.3 (S2), R39.2, R40.1
unnamed: R34.2, U9.4
unnamed: R35.2, U10.4
unnamed: R44.1, U11.4 (+)
unnamed: R45.1, U11.3 (-)

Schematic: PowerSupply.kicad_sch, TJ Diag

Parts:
C17, C21, C22: 2u2; C_0603_1608Metric
C18: 0u33; C_0603_1608Metric
C19, C20: 1u; C_0603_1608Metric
U5: NCV7808BDTRKG; TO-252-2
U6: TLV76150DCYR; SOT-223-3_TabPin2
U7: TLV76133DCYR; SOT-223-3_TabPin2

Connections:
+3V3: C22.1, U7.2 (VO); also elsewhere on the board
+5V: C21.1, U6.2 (VO); also elsewhere on the board
+8V: C17.1, U5.3 (OUT); also elsewhere on the board
GND: C17.2, C18.2, C19.2, C20.2, C21.2, C22.2, U5.2 (GND), U6.1 (GND), U7.1 (GND); also elsewhere on the board

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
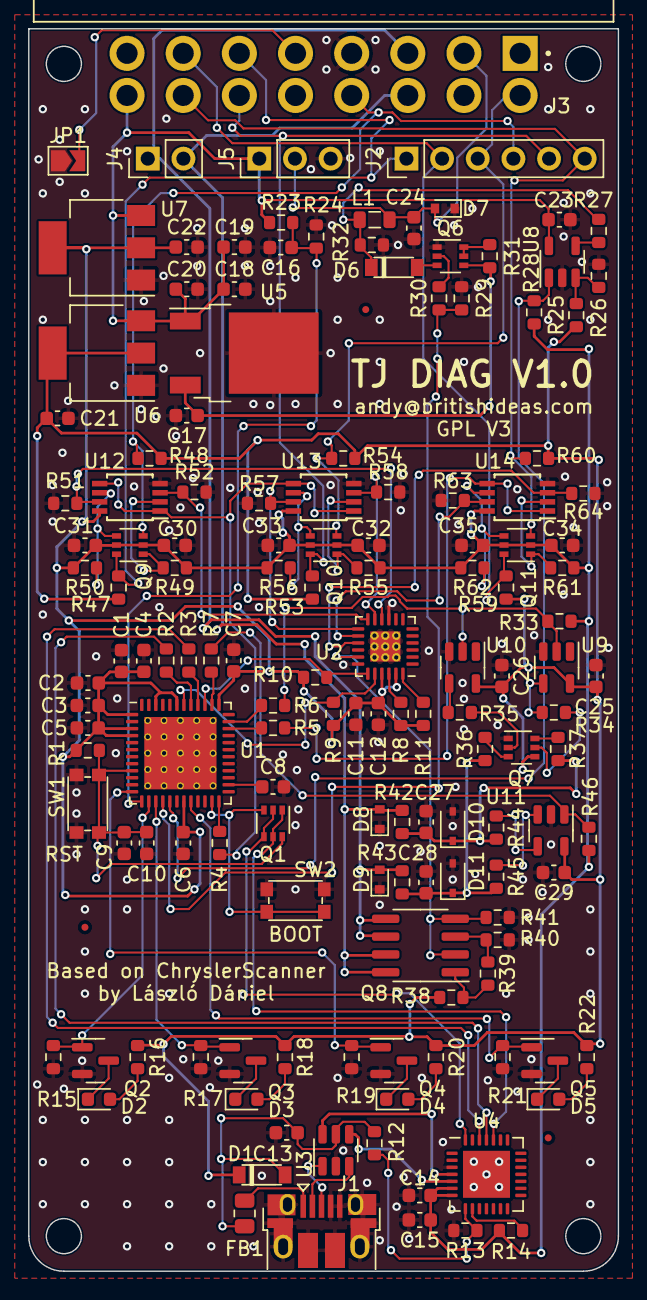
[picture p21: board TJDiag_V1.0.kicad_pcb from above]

Board: 2 copper layers, 42.0 x 88.5 mm, 148 parts (0 on the bottom side), 90 nets.

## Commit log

2023-06-25 Working on re-creating schematic. Added 10nF capacitor and ferrite bead near USB connector.
    [ChryslerScanner_V210.kicad_pcb, ChryslerScanner_V210.kicad_sch, LEDs.kicad_sch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]
2023-06-25 Added schematic symbol library needed for V210 schematic.
2023-06-25 Added power supplies. Removed CCD.
    [ChryslerScanner_V210.kicad_sch, LEDs.kicad_sch, MCU.kicad_sch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]
2023-06-25 Completed schematic.
    [ChryslerScanner_V210.kicad_sch, LEDs.kicad_sch, MCU.kicad_sch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]
2023-07-02 Added file that was deleted by mistake.
    [PowerSupply.kicad_sch]
2023-07-02 Updated schematic
    [MCU.kicad_sch, PowerSupply.kicad_sch]
2023-07-07 Working on power supplies. Added datasheets.
    [ChryslerScanner_V210.kicad_sch, MCU.kicad_sch, PowerSupply.kicad_sch]
2023-07-07 Added OBD-II connector.
    [C-OBD-II-16M.step, ChryslerScanner_V210.kicad_sch, LEDs.kicad_sch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]
2023-07-09 Added CCD back in - needed for early TJs.
    [ChryslerScanner_V210.kicad_sch, LEDs.kicad_sch, MCU.kicad_sch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]
2023-07-19 Final component assignments.
    [ChryslerScanner_V210.kicad_sch, LEDs.kicad_sch, MCU.kicad_sch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]
2023-09-10 Working on PCB layout. Deleted old versions.
    [CCD.kicad_sch, ChryslerCCDSCIScanner_V142_box.STEP, ChryslerScanner_V210.kicad_pcb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]
2023-09-12 Working on PCB layout.
    [ChryslerScanner_V210.kicad_pcb]
2023-09-13 Added Jeep TJ silhouette to bottom of board.
    [ChryslerScanner_V210.kicad_pcb]
2023-09-13 Added step model.
    [ChryslerScanner_V210.kicad_pcb]
2023-09-13 Renamed folder.
    [CCD.kicad_sch, ChryslerScanner_V210.kicad_pcb, ChryslerScanner_V210.kicad_sch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]
2023-09-14 Added Alibre Design files for PCB and started work on case.
    [ChryslerScanner_V210.kicad_pcb]
2023-09-14 Renamed folder
    [CCD.kicad_sch, ChryslerScanner_V210.kicad_pcb, ChryslerScanner_V210.kicad_sch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]
2023-09-14 Renamed KiCAD project.
    [TJDiag_V1.0.kicad_pcb, TJDiag_V1.0.kicad_sch]
2023-09-14 Deleted old schematics
2023-09-15 Completed case design.
2023-09-22 Reformatted schematic pages to US Letter. Generated schematic PDF.
    [CCD.kicad_sch, LEDs.kicad_sch, MCU.kicad_sch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]
